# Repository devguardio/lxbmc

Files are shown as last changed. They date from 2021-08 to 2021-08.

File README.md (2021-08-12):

# lxbmc

board managment controller for the solid-run honeycomb arm server

 - screws into a 2.5' drive bay
 - controlls power on.off
 - usb for virtual ethernet and disk
 - access the cpus local serial terminal remotely

# setup

after installing ubuntu with the usual usbboot thing:

    echo 'dtoverlay=dwc2,dr_mode=peripheral' >> /boot/firmware/config.txt

    systemctl stop serial-getty@ttyS0.service
    systemctl mask serial-getty@ttyS0.service

    systemctl stop systemd-resolved
    systemctl disable systemd-resolved
    rm /etc/resolv.conf
    echo nameserver 8.8.8.8 >  /etc/resolv.conf
    apt install dnsmasq
    systemctl stop dnsmasq
    systemctl disable dnsmasq

then install starfeldt bmc and config as:

    [power]
    switch='gpio5'

    [serial]
    device='/dev/ttyS0'

    [usb]

or if you're not a devguard customer maybe look at pikvm.org for a free alternative

# fan

https://github.com/neg2led/cm4io-fan

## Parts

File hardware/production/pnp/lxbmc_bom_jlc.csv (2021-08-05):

Comment | Designator | Footprint | LCSC Part #
100n | C3 | C_0603_1608Metric
C | C1 | C_0603_1608Metric
C | C2 | C_0805_2012Metric
LED | D1 | LED_0603_1608Metric
0826-1X1T-GH-F | J3 | BEL_0826-1X1T-GH-F
7790 | J5,J6,J7,J8 | 7790
Conn_02x05_Odd_Even | J1 | PinHeader_2x05_P2.54mm_Vertical
Screw_Terminal_01x03 | J4 | TerminalBlock_MetzConnect_Type059_RT06303HBWC_1x03_P3.50mm_Horizontal
Screw_Terminal_01x04 | J2,J9 | TerminalBlock_MetzConnect_Type059_RT06304HBWC_1x04_P3.50mm_Horizontal
470 | R1,R2,R3,R4 | R_0603_1608Metric
G3VM-61G1 | RLA1 | G3VM-61G1 | C38724
RPI4CM | U1 | rpiCM4
DF40HC_3.0_-100DS-0.4V_51_PNP_OVERLAY | X1,X2 | HRS_DF40HC(3.0)-100DS-0.4V(58)_PNP_OVERLAY | C424649

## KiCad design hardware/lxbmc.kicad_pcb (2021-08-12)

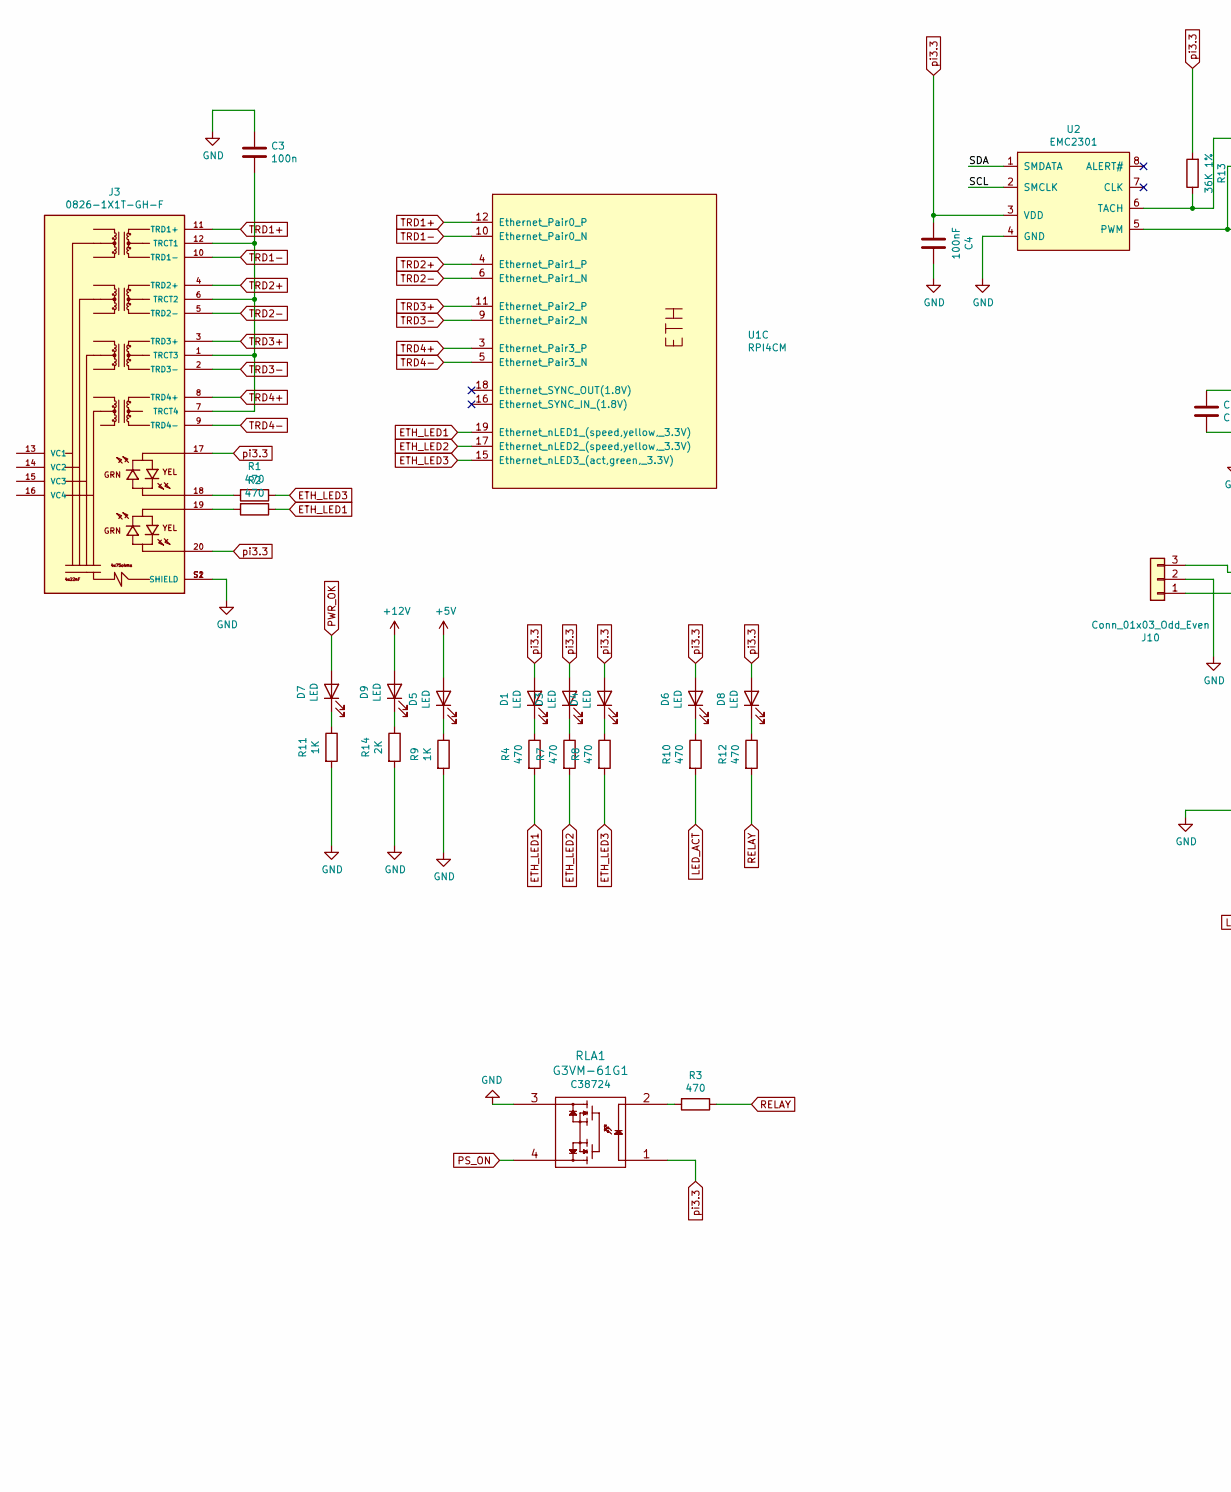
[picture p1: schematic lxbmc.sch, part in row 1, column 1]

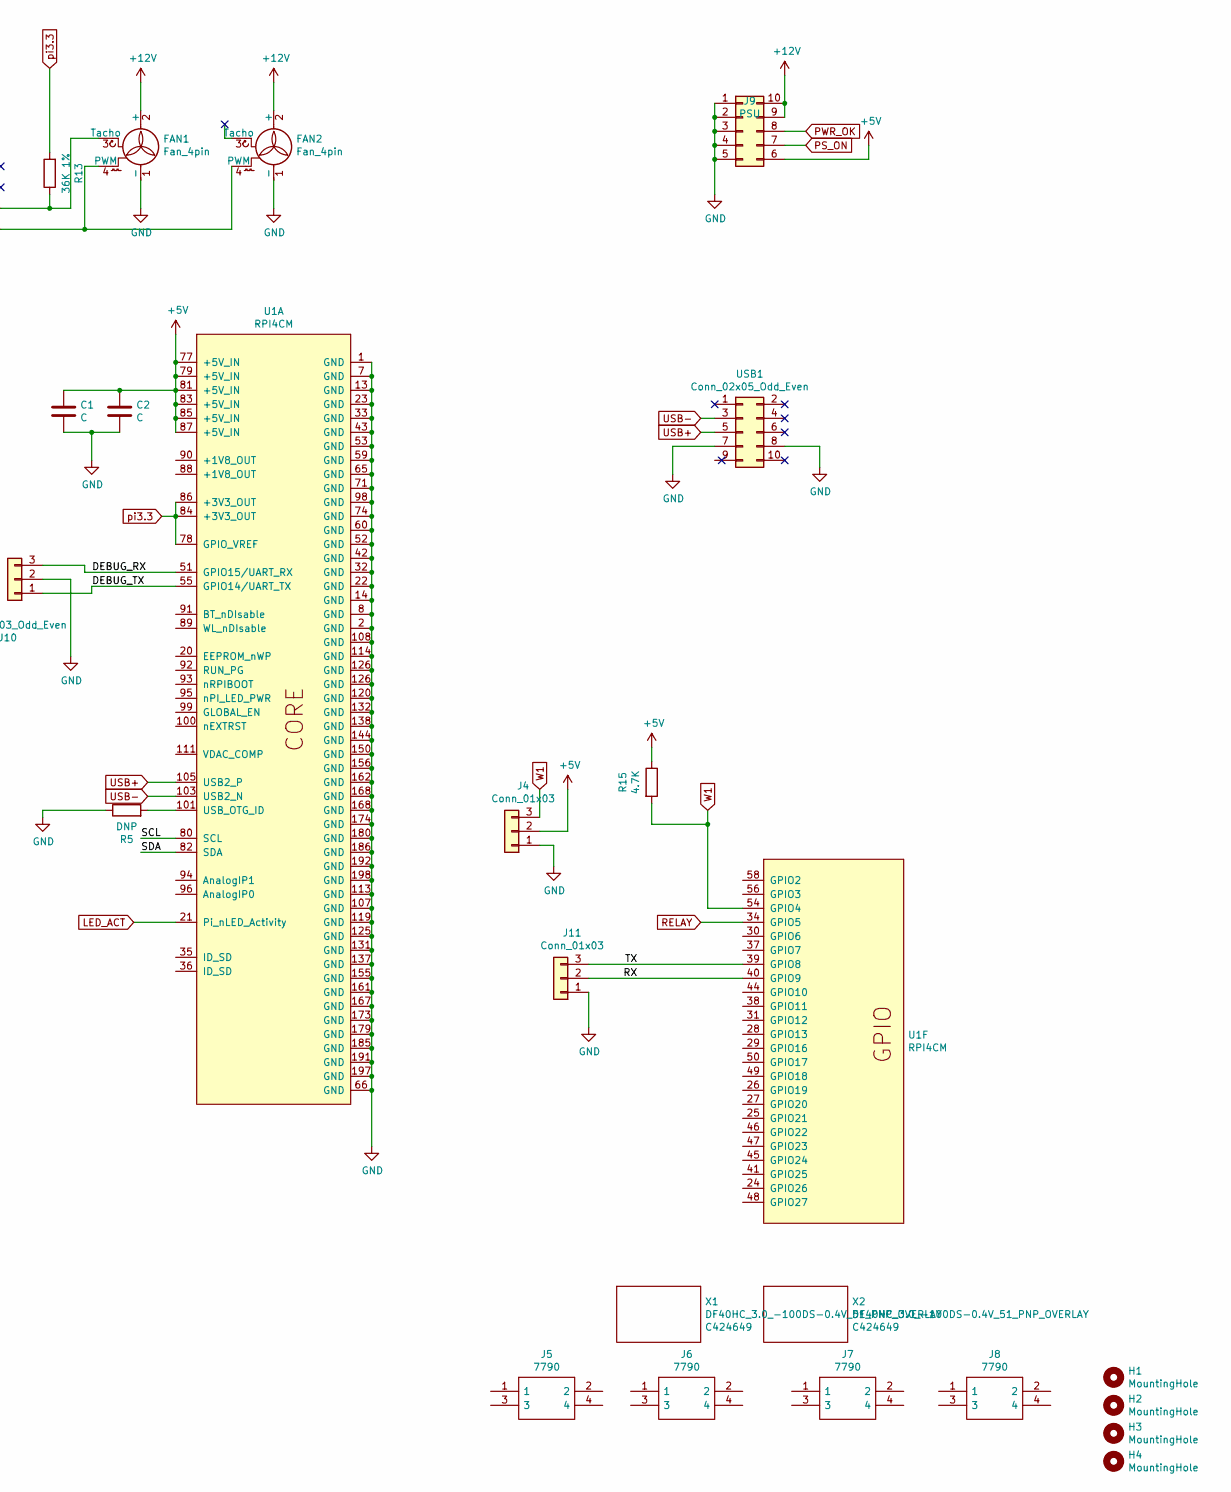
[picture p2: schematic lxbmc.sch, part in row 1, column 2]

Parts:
C1: C; C_0603_1608Metric; JLC# C14858
C2: C; C_0805_2012Metric; JLC# C15850
C3: 100n; C_0603_1608Metric
C4: 100nF; C_0603_1608Metric
D1, D6, D7, D8: LED; LED_0402_1005Metric; JLC# C130723
D3: LED; LED_0402_1005Metric; JLC# C130721
D4: LED; LED_0402_1005Metric; JLC# C688877
D5, D9: LED; LED_0402_1005Metric; JLC# C397045
FAN1, FAN2: Fan_4pin; Molex_KK-254_AE-6410-04A_1x04_P2.54mm_Vertical
H1, H2, H3, H4: MountingHole; MountingHole_3.2mm_M3_DIN965_Mask
J3: 0826-1X1T-GH-F; BEL_0826-1X1T-GH-F
J4, J11: Conn_01x03; Molex_KK-254_AE-6410-03A_1x03_P2.54mm_Vertical
J5, J6, J7, J8: 7790; Manufacturer_Part_Number 7790; Mouser Part Number 534-7790
J9: PSU; Molex_Mini-Fit_Jr_5566-10A_2x05_P4.20mm_Vertical
J10: Conn_01x03_Odd_Even; PinHeader_1x03_P2.54mm_Vertical
R1, R2, R3, R4, R7, R8, R10, R12: 470; R_0402_1005Metric; LCSC# C25117
R5: DNP; R_0402_1005Metric
R9, R11: 1K; R_0402_1005Metric
R13: 36K 1%; R_0402_1005Metric; JLC# C43676
R14: 2K; R_0402_1005Metric
R15: 4.7K; R_0402_1005Metric; JLC# C25900
RLA1: G3VM-61G1; G3VM-SOP; LCSC# C38724
U1: RPI4CM; rpi_cm4
U2: EMC2301; MSOP-8_3x3mm_P0.65mm; LCSC# C148036
USB1: Conn_02x05_Odd_Even; PinHeader_2x05_P2.54mm_Vertical
X1, X2: DF40HC_3.0_-100DS-0.4V_51_PNP_OVERLAY; HRS_DF40HC(3.0)-100DS-0.4V(58)_PNP_OVERLAY; Manufacturer_Part_Number DF40HC(3.0)-100DS-0.4V(51; Mouser Part Number 798-DF40HC30100DS451

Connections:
+5V: C1.1, C2.1, D5.2 (A), J4.2, J9.6, R15.1, U1.77 (+5V_IN), U1.79 (+5V_IN), U1.81 (+5V_IN), U1.83 (+5V_IN), U1.85 (+5V_IN), U1.87 (+5V_IN)
+12V: D9.2 (A), FAN1.2 (+), FAN2.2 (+), J9.9, J9.10
/DEBUG_RX: J10.3, U1.51 (GPIO15/UART_RX)
/DEBUG_TX: J10.1, U1.55 (GPIO14/UART_TX)
/RX: J11.2, U1.40 (GPIO9)
/SCL: U1.80 (SCL), U2.2 (SMCLK)
/SDA: U1.82 (SDA), U2.1 (SMDATA)
/TX: J11.3, U1.39 (GPIO8)
ETH_LED1: R2.1, R4.2, U1.19 (Ethernet_nLED1_(speed,yellow,_3.3V))
ETH_LED2: R7.2, U1.17 (Ethernet_nLED2_(speed,yellow,_3.3V))
ETH_LED3: R1.1, R8.2, U1.15 (Ethernet_nLED3_(act,green,_3.3V))
GND: C1.2, C2.2, C3.1, C4.2, FAN1.1 (-), FAN2.1 (-), J3.S1 (SHIELD), J3.S2 (SHIELD), J4.1, J9.1, J9.2, J9.3, J9.4, J9.5, J10.2, J11.1, R5.1, R9.2, R11.2, R14.2, RLA1.3, U1.1 (GND), U1.2 (GND), U1.7 (GND), U1.8 (GND), U1.13 (GND), U1.14 (GND), U1.22 (GND), U1.23 (GND), U1.32 (GND), U1.33 (GND), U1.42 (GND), U1.43 (GND), U1.52 (GND), U1.53 (GND), U1.59 (GND), U1.60 (GND), U1.65 (GND), U1.66 (GND), U1.71 (GND), U1.74 (GND), U1.98 (GND), U1.107 (GND), U1.108 (GND), U1.113 (GND), U1.114 (GND), U1.119 (GND), U1.120 (GND), U1.125 (GND), U1.126 (GND), U1.131 (GND), U1.132 (GND), U1.137 (GND), U1.138 (GND), U1.144 (GND), U1.150 (GND), U1.155 (GND), U1.156 (GND), U1.161 (GND), U1.162 (GND), U1.167 (GND), U1.168 (GND), U1.173 (GND), U1.174 (GND), U1.179 (GND), U1.180 (GND), U1.185 (GND), U1.186 (GND), U1.191 (GND), U1.192 (GND), U1.197 (GND), U1.198 (GND), U2.4 (GND), USB1.7, USB1.8
LED_ACT: R10.2, U1.21 (Pi_nLED_Activity)
unnamed: C3.2, J3.1 (TRCT3), J3.6 (TRCT2), J3.7 (TRCT4), J3.12 (TRCT1)
unnamed: D1.1 (K), R4.1
unnamed: D3.1 (K), R7.1
unnamed: D4.1 (K), R8.1
unnamed: D5.1 (K), R9.1
unnamed: D6.1 (K), R10.1
unnamed: D7.1 (K), R11.1
unnamed: D8.1 (K), R12.1
unnamed: D9.1 (K), R14.1
unnamed: FAN1.3 (Tacho), R13.1, U2.6 (TACH)
unnamed: FAN1.4 (PWM), FAN2.4 (PWM), U2.5 (PWM)
unnamed: J3.18, R1.2
unnamed: J3.19, R2.2
unnamed: R3.2, RLA1.2
unnamed: R5.2, U1.101 (USB_OTG_ID)
PS_ON: J9.7, RLA1.4
PWR_OK: D7.2 (A), J9.8
RELAY: R3.1, R12.2, U1.34 (GPIO5)
TRD1+: J3.11 (TRD1+), U1.12 (Ethernet_Pair0_P)
TRD1-: J3.10 (TRD1-), U1.10 (Ethernet_Pair0_N)
TRD2+: J3.4 (TRD2+), U1.4 (Ethernet_Pair1_P)
TRD2-: J3.5 (TRD2-), U1.6 (Ethernet_Pair1_N)
TRD3+: J3.3 (TRD3+), U1.11 (Ethernet_Pair2_P)
TRD3-: J3.2 (TRD3-), U1.9 (Ethernet_Pair2_N)
TRD4+: J3.8 (TRD4+), U1.3 (Ethernet_Pair3_P)
TRD4-: J3.9 (TRD4-), U1.5 (Ethernet_Pair3_N)
USB+: U1.105 (USB2_P), USB1.5
USB-: U1.103 (USB2_N), USB1.3
W1: J4.3, R15.2, U1.54 (GPIO4)
pi3.3: C4.1, D1.2 (A), D3.2 (A), D4.2 (A), D6.2 (A), D8.2 (A), J3.17, J3.20, R13.2, RLA1.1, U1.78 (GPIO_VREF), U1.84 (+3V3_OUT), U1.86 (+3V3_OUT), U2.3 (VDD)

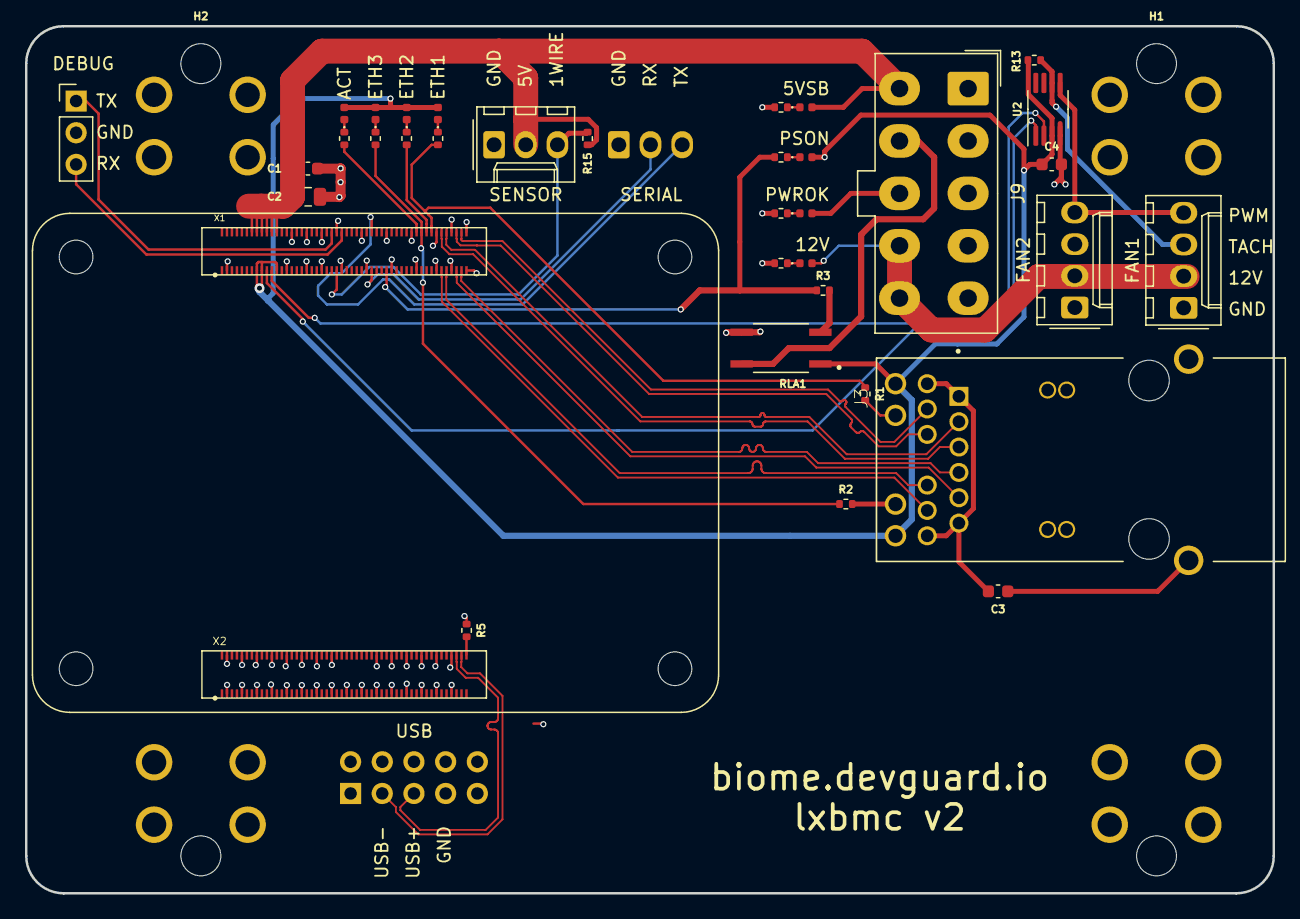
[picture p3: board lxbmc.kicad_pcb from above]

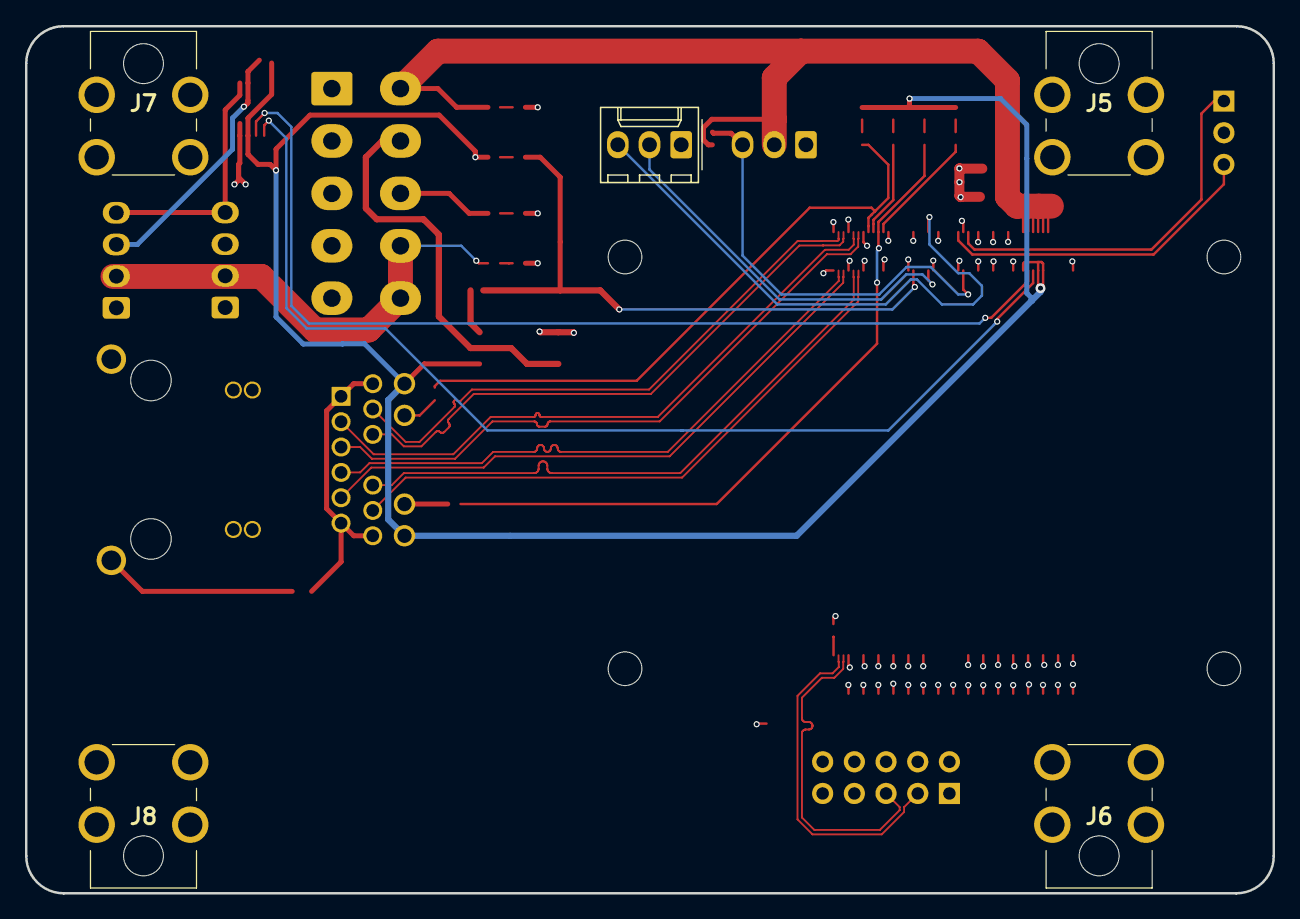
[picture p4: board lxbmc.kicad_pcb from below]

Board: 4 copper layers, 100.0 x 69.5 mm, 47 parts (5 on the bottom side), 43 nets.
